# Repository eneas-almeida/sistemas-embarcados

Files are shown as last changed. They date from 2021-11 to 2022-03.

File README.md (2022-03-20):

# Sistemas Embarcados - 2021.2



## 1. Instituição

-   Instituto Federal da Paraíba - IFPB
-   Campus Campina Grande

## 2. Docente responsável

-   [Professor Dr. Alexandre Sales Vasconcelos](https://github.com/alexandresvifpb)

## 3. Grupo

-   [Edivam Enéas de Almeida Júnior](https://github.com/venzel)
-   [Erickson Tulio Rodrigues Azevêdo](https://github.com/Erickson-Eng)
-   [Joab da Silva Maia](https://github.com/JoabMaia)

## 4. Descrição do projeto

Nesse projeto foi realizado desenvolvimento de um sistema embarcado que é capaz de identificar vazamento de gases, além disso, também apresenta todas as informações desse vazamento a partir de um display led e faz envio de mensagens SMS para celulares cadastrados em uma aplicação integrada.

## 5. Objetivos

### 5.1. Geral

-   O objetivo geral deste trabalho é o desenvolvimento de uma hardware de segurança doméstica para fornecer um sinal de alarme ao usuário caso aconteça vazamento de gás, além de informações na tela de temperatura.

### 5.2. Específicos

-   Criar um prototipo que seja capaz de realizar detecção de gás, apresentação de resultados via display e também conseguir realizar envio de mensagens SMS para o dispositivo cadastrado.

## 6. Resumo das arquiteturas

A seguir é no tópico 1 _Hardware_ é apresentado a placa e o case ambos construídos no aplicativo fusion 360 e em seguida no tópico 2 _Firmaware e/ou Software/App_ é apresentado as especificações como circuito eletrico e PCB.

### 6.1. Desenhos

-   3D

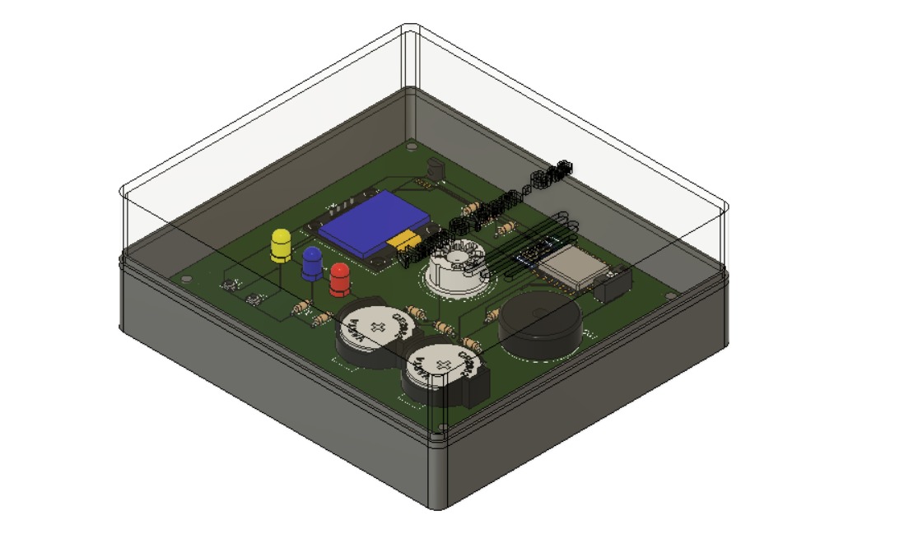
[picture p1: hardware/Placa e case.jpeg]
Placa e Case completo


-   PCB

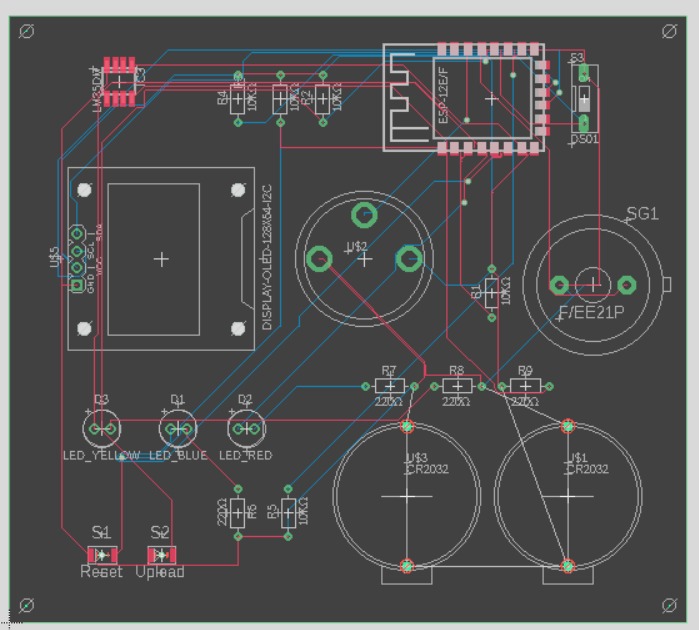
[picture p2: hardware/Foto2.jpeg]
foto


-   Circuito elétrico

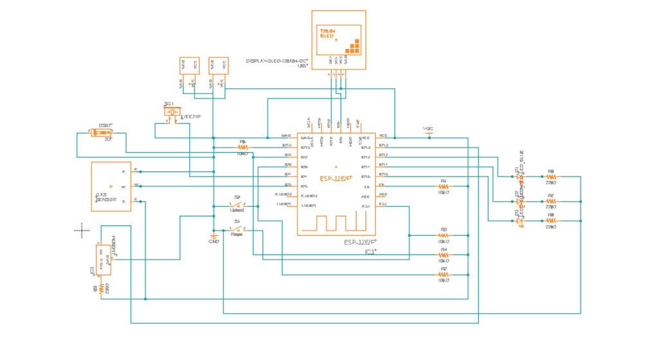
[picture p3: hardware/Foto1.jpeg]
foto 2


## 7. Firmwares

👉 [Teste do display lcd com I2C](./firmwares/teste_lcd_I2C/teste_lcd_I2C.ino)<br />
👉 [Teste do sensor de temperatura](./firmwares/teste_sensor_temperatura/teste_sensor_temperatura.ino)<br />
👉 [Teste do sensor de gás](./firmwares/teste_sensor-gas/teste_sensor-gas.ino)<br />
👉 [Teste da conexão com o wifi](./firmwares/teste_wifi/teste_wifi.ino)<br />
👉 [Código do projeto (v1)](./firmwares/codigo_final_projeto/codigo_final_projeto.ino)<br />
👉 [Código do projeto (v2)](./firmwares/projeto)

## 8. Vídeo do protótipo

Vídeo do protótipo (https://www.youtube.com/watch?v=XGZ1nPyMRSw)

## 9. Vídeo da apresentação

Vídeo do protótipo (https://www.youtube.com/watch?v=j182I6oHwiY)

## 10. Diagrama de processo

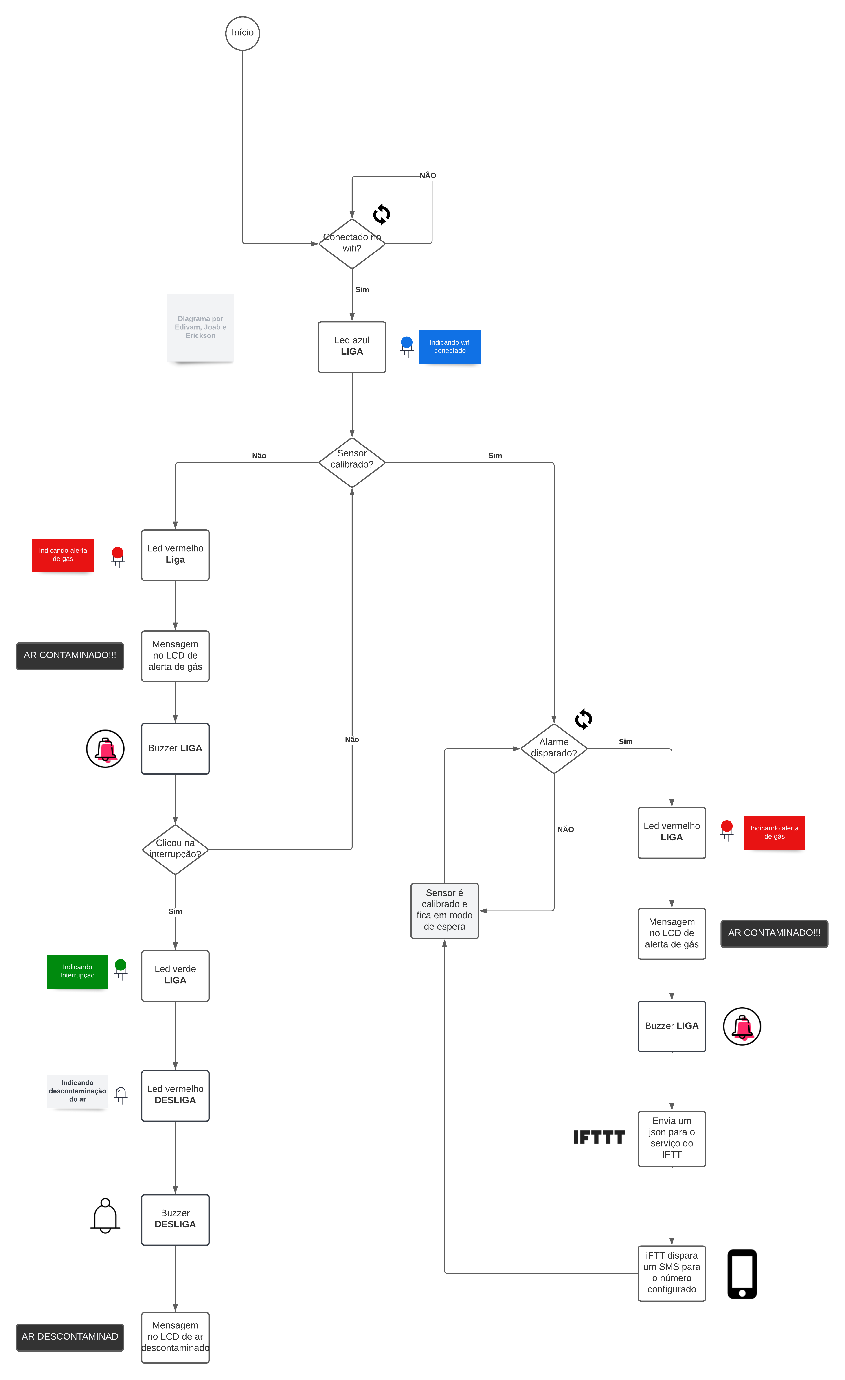
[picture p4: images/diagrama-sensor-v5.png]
Diagrama de processo


## 11. Diagrama de bloco

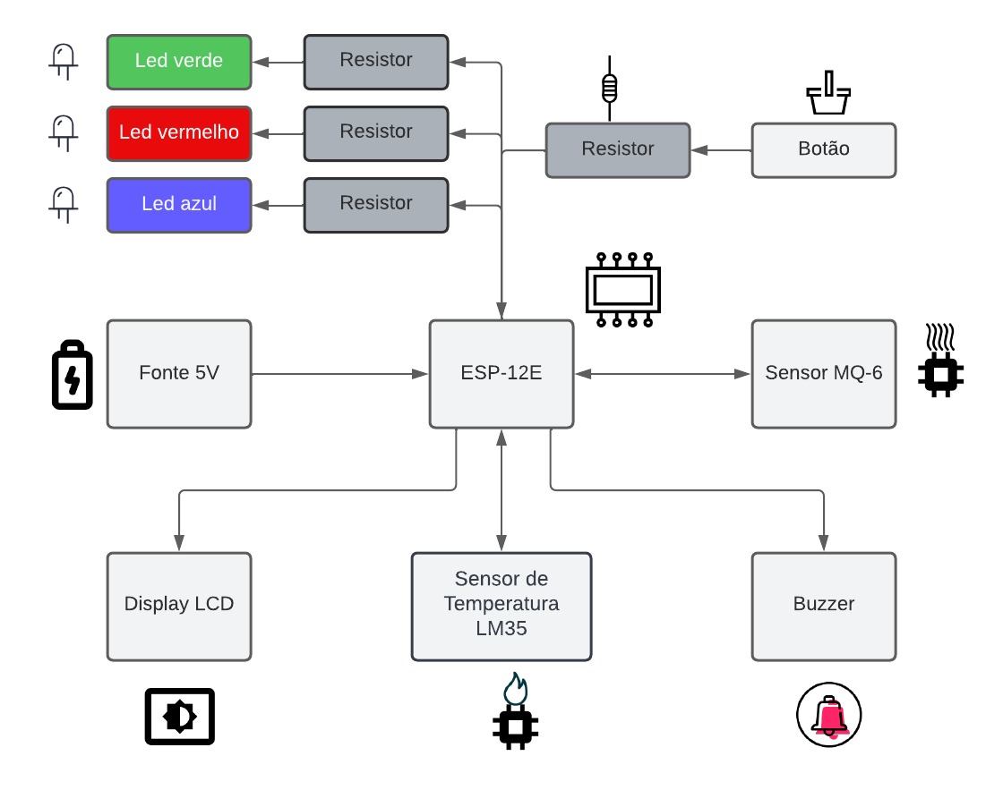
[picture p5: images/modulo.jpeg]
Diagrama de bloco


## 12. Resumo dos Resultados

Nesse projeto foi possível construir um protótipo capaz de realizar a detecção de gases inflamáveis, além disso, através do sistema é possível disparar alertas tanto para sua própria interface que é um componente LCD de 16 colunas e duas linhas, um alto-falante para emitir sinais sonoros e por fim interfaces externas com o uso de mensagem via SMS.



Outro recurso importante que também implementado foi a integração do sistema com uma api de envio de SMS, o **IFTT**, onde é possível através de uma chamada JSON, se comunicar com o serviço e efetuar disparos de SMS.

**Foi possível atingir os seguintes objetivos adicionais:**

-   Implementar sistema de interrupções.
-   Instalação de libs dos módulos.
-   Realizar a implementação de threads.

👉 [Relatório final do projeto (PDF)](./results/relatorio-final.pdf)<br />

## 13. Link dos arquivos

👉 [Esquema elétrico (EAGLE)](./3d/projeto_dispositivo_alarme_gas/esquema_eletrico/esquema_eletrico_eagle.sch)<br />
👉 [Esquema elétrico (FUSION)](./3d/projeto_dispositivo_alarme_gas/esquema_eletrico/esquema_eletrico_fusion.fsch)<br />
👉 [Imagens com furos da PCB (PARTE INFERIOR)](./3d/projeto_dispositivo_alarme_gas/imagem_bottom_side_da_pcb_manufacturing/imagem_bottom_side_da_pcb_manufacturing.png)<br />
👉 [Imagens com furos da PCB (PARTE SUPERIOR)](./3d/projeto_dispositivo_alarme_gas/imagem_top_side_da_pcb_manufacturing/imagem_top_side_da_pcb_manufacturing.png)<br />
👉 [Medidas dos furos da PCB (1)](./3d/projeto_dispositivo_alarme_gas/imagem_drils_da_pcb/imagem_drils_da_pcb.png)<br />
👉 [Medidas dos furos da PCB (2)](./3d/projeto_dispositivo_alarme_gas/imagem_drils_da_pcb/metricas_drills.csv)<br />
👉 [Layout da PCB (EAGLE)](./3d/projeto_dispositivo_alarme_gas/layout_da_pcb/layout_da_pcb_eagle.brd)<br />
👉 [Layout da PCB (FUSION)](./3d/projeto_dispositivo_alarme_gas/layout_da_pcb/layout_da_pcb_fusion.fbrd)<br />
👉 [Desenho 3D - Apenas PCB (FUSION)](./3d/projeto_dispositivo_alarme_gas/modelo_3d_da_pcb/modelo_3d_da_pcb.f3d)<br />
👉 [Desenho 3D - PCB + CASE (FUSION)](./3d/projeto_dispositivo_alarme_gas/modelo_3d_da_pcb/modelo_3d_da_pcb_e_case.f3z)

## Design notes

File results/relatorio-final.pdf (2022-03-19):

Instituto Federal de Educação, Ciência e Tecnologia da Paraíba.

Campus Campina Grande

Disciplina: Sistemas Embarcados

Professor: Alexandre Sales Vasconcelos

Equipe: Edivam Enéas de Almeida Junior,

Joab da Silva Maia,

Erickson Tulio Rodrigues Azevêdo.

# Sistema para monitorar vazamentos de gases e exposição

a alta temperaturas.

Resumo

Esse relatório tem como objetivo descrever o desenvolvimento do

protótipo que foi criado na disciplina de sistemas embarcados, no qual atua como

um sistema para prevenção de incêndios realizando a detecção de vazamento

de gases e, além disso, também verifica se existe aumentos de temperaturas

fora do normal no ambiente onde se encontra instalado. Para que tornasse

possível o desenvolvimento de tal solução foi necessário verificar o problema a

fundo e verificar sua viabilidade, dessa forma, realizamos uma pesquisa para

identificar o índice de acidentes domésticos e em empresas e decidimos a

abordagem que seria criar um sistema para uso doméstico.

Palavras-Chaves: | Esp32, | Prevenção | de | incêndios, | sistemas

embarcados, comunicação

### 1. Introdução

### 1.1. Acidentes domésticos com gás inflamável

Diante dos grandes acidentes causados, na maioria das vezes, por falta de

cuidados básicos e cumprimentos de normas técnicas a fim da prevenção de

acidentes e explosões causados por vazamentos de gás.

Dados estatísticos do corpo de bombeiros localizado no Estado de São

Paulo refletem bem essa problemática, enumerando os atendimentos prestados,

de simples vazamentos de botijões de gás até verdadeiras catástrofes causadas

por explosões residenciais (casas, prédios) e até mesmo nas indústrias.

Em meados de 2015, no Estado de São Paulo, o Corpo de Bombeiros

marcou 4.055 casos de acidentes por decorrência do vazamento do gás

conhecido como Gás Liquefeito de Petróleo ou simplesmente GLP. Como já

mencionado, isso se dá por pura negligência das pessoas que vão instalar uma

simples válvula em seu fogão até a falta de fiscalização das tubulações dos

grandes edifícios, empresas e fábricas.

A Figura 1 apresenta um exemplo do que pode causar problemas com

vazamento de gás, esse por sua vez ocorreu em 19 de outubro de 2015 no Bairro

de São Cristóvão, na Zona Norte do Rio de Janeiro.

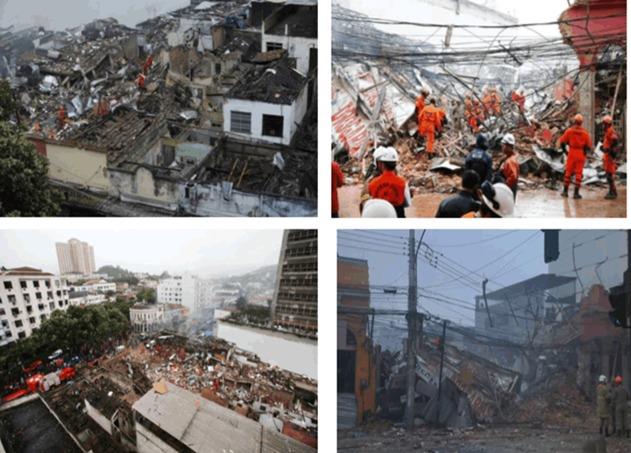
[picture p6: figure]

Figura 1. Acidente no Rio de Janeiro causado por vazamento de gás.

(Fonte: G1)

Nesse contexto, o objetivo desse trabalho é desenvolver um sistema

embarcado que seja capaz de realizar a detecção de gases e de aumentos da

temperatura e disparar alertas para assim, conseguir mais uma camada de

proteção e prevenção para população para esse tipo de acidentes.

### 2. Metodologia

O presente trabalho apresenta o desenvolvimento de um protótipo de

sistema embarcado cujo o público alvo são ambientes domésticos. Para obter

um melhor embasamento cientifico, foram realizados estudos bibliográficos para

conhecer os riscos do gás GLP, além disso, foram realizados levantamento

sobre as ferramentas e tecnologias necessárias para a construção do mesmo.

### 2.1. Tecnologias

Durante o desenvolvimento do projeto foi realizado um levantamento de

todos os materiais que seriam necessários para fazer um protótipo útil e funcional onde após realizar a instalação do mesmo no local apropriado seria possível

obter os devidos resultados.

### 2.1.1. Lista dos principais materiais utilizados para

produção do protótipo

- Módulo NodeMCU ESP-12E - é uma placa que junta o

ESP8266 (chip de arquitetura 32 bits com WiFi integrado), interface USB-

Serial e regulador de tensão 3,3V. A programação pode ser feita usando

LUA ou a IDE do Arduino, utilizando a comunicação via cabo micro-usb

- Sensor de MQ-6 - é um detector de gás inflamável é usado

como dispositivo de segurança em projetos de automação residencial que

usam como base plataformas de prototipagem, como Arduino ou

Raspberry PI.

- Buzzer - é um pequeno alto-falante destinado a emitir sinais

sonoros a partir do fornecimento de 5V DC ao módulo, não necessita de

nenhum componente externo para gerar sinal ou oscilação, basta

alimentar com corrente

- Display LCD 16x2 Backlight Azul - é um visor de 16

colunas por 2 linhas, backlight azul e escrita branca. Possui o controlador

HD44780 usado em toda indústria de LCD’s como base de interface.

- I2C para Display LCD - este é um módulo para

comunicação por protocolo I2C, é utilizado em displays LCD 16X2 ou

20x4. Com este módulo é possível ocupar apenas duas portas do

microcontrolador, pois dos quatro pinos de saída, dois são para

alimentação de 5Volts. DHT11 - Este sensor é ideal para fazer a leitura

de umidade e temperatura e informar ao microcontrolador como um

Arduino. Ele possui saída de sinal digital garantindo alta confiabilidade e

estabilidade a longo prazo.

- Protoboard - Uma placa de ensaio ou matriz de contato,

(breadboard em inglês) é uma placa com furos (ou orifícios) e conexões

condutoras para montagem de circuitos elétricos experimentais

- Leds – Utilizados para sinalização visual.
- Resistores de 300 ohms

- Jumper tipo macho-macho e macho-fêmea – Utilizado

para conectar os componentes do protótipo.

- Caixa em MDF – Utilizados para criar um suporte para os

sensores e Shields do protótipo.

Figura 2 Diagrama de protótipo

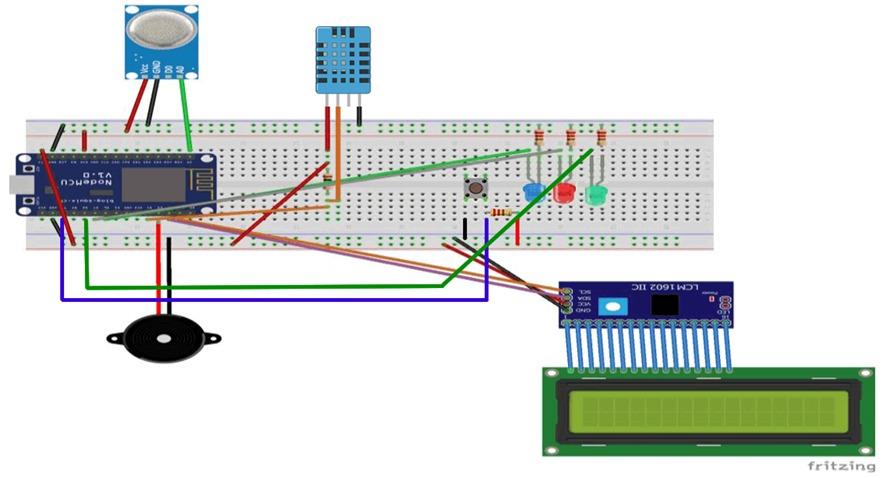
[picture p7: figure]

Fonte 1 Elaborado pelo autor (2022)

Na Figura 2 é apresentado a organização inicial de como ficará o protótipo

ao realizar todas as ligações entre os componentes em sua versão inicial.

Desenvolvimento

### 2.2. O protótipo

Esse projeto possui como diferencial a criação de um sistema de baixo

custo de produção para conseguir atender pessoas em situação social critica.

Para isso, se fez necessário identificar quais os cenários que nosso protótipo

conseguiria atuar.

Na Figura 3 é apresentado um fluxograma do funcionamento do sistema

demonstrando sua linha de raciocínio para suas decisões a ações.

Figura 3- Fluxograma do funcionamento do sistema

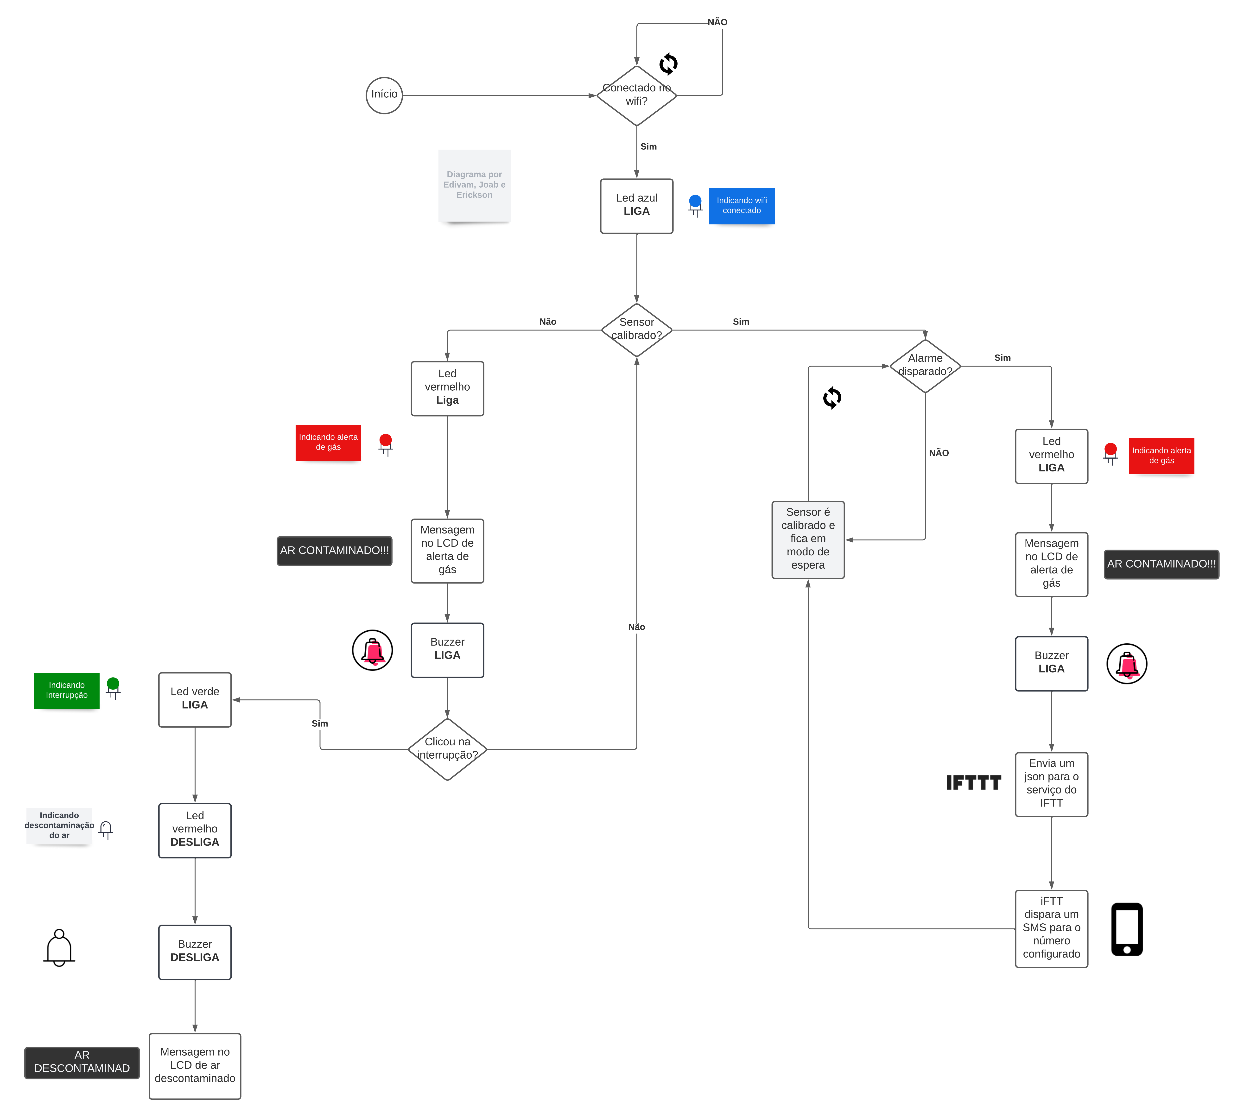
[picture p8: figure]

Fonte 2- Elaborado pelos autores (2022)

Na Figura 3 é possível verificar o funcionamento do sistema onde o

mesmo precisa se conectar com uma rede wifi para realizar a calibragem dos

sensores. Após todo o sistema estar calibrado o mesmo passa a realizar

verificação do ar buscando princípios de contaminação, caso exista

contaminação o sistema dispara duas ações onde é a primeira é alerta sonoro e

iniciado em seguida também um contato com sistema de envio de mensagens

SMS para envio de um relatório para o numero cadastrado no sistema

informando sobre a contaminação ou alteração na temperatura no local que está

instalado o protótipo.

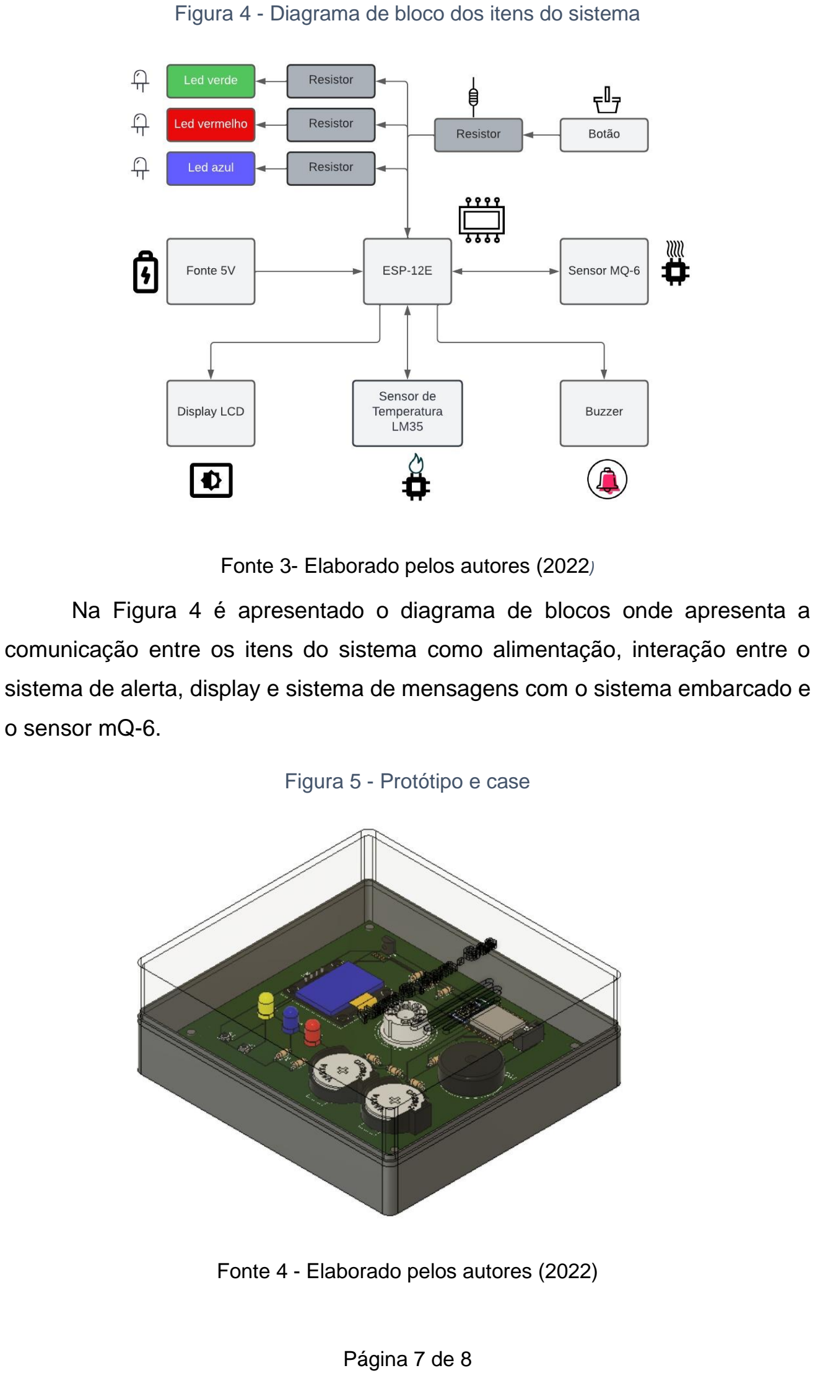
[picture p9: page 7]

Figura 4 - Diagrama de bloco dos itens do sistema

Fonte 3- Elaborado pelos autores (2022)

Na Figura 4 é apresentado o diagrama de blocos onde apresenta a

comunicação entre os itens do sistema como alimentação, interação entre o

sistema de alerta, display e sistema de mensagens com o sistema embarcado e

o sensor mQ-6.

Figura 5 - Protótipo e case

Fonte 4 - Elaborado pelos autores (2022)

Na Figura 5 é apresentado uma imagem do protótipo 3d criada no Fusion 360 onde representa o objeto desse estudo mostrando como ficará organizado como um produto.

### 3. Resultados

O presente trabalho teve como objetivos propor e desenvolver um sistema

embarcado capaz de identificar se existe contaminação no ar e em prontidão

passar a informação para seu usuário seja por mensagem de texto ou alerta

sonoros.

Esses objetivos foram alcançados, além disso, foi proposto também pelo

professor Alexandre a implementação de threads e um sistema de interrupções

no desenvolvimento no iria possibilitar melhorias que também foram

prontamente realizadas.

Para desenvolvimento futuro fica o desafio de montar um sistema de baixo

custo que possibilite realizar mais ações além das citadas nessa problemática

como o controle do fluxo de gás do fogão.

### 4. Referências bibliográficas

https://www.arduino.cc/reference/pt/

http://automatizacg.com

http://fritzing.org/home

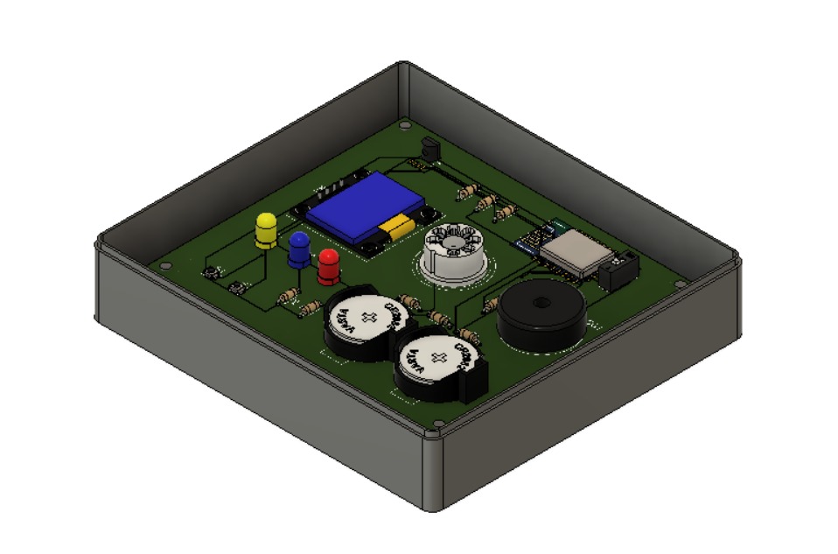
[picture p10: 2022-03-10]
hardware/Placa sem case superior.jpeg

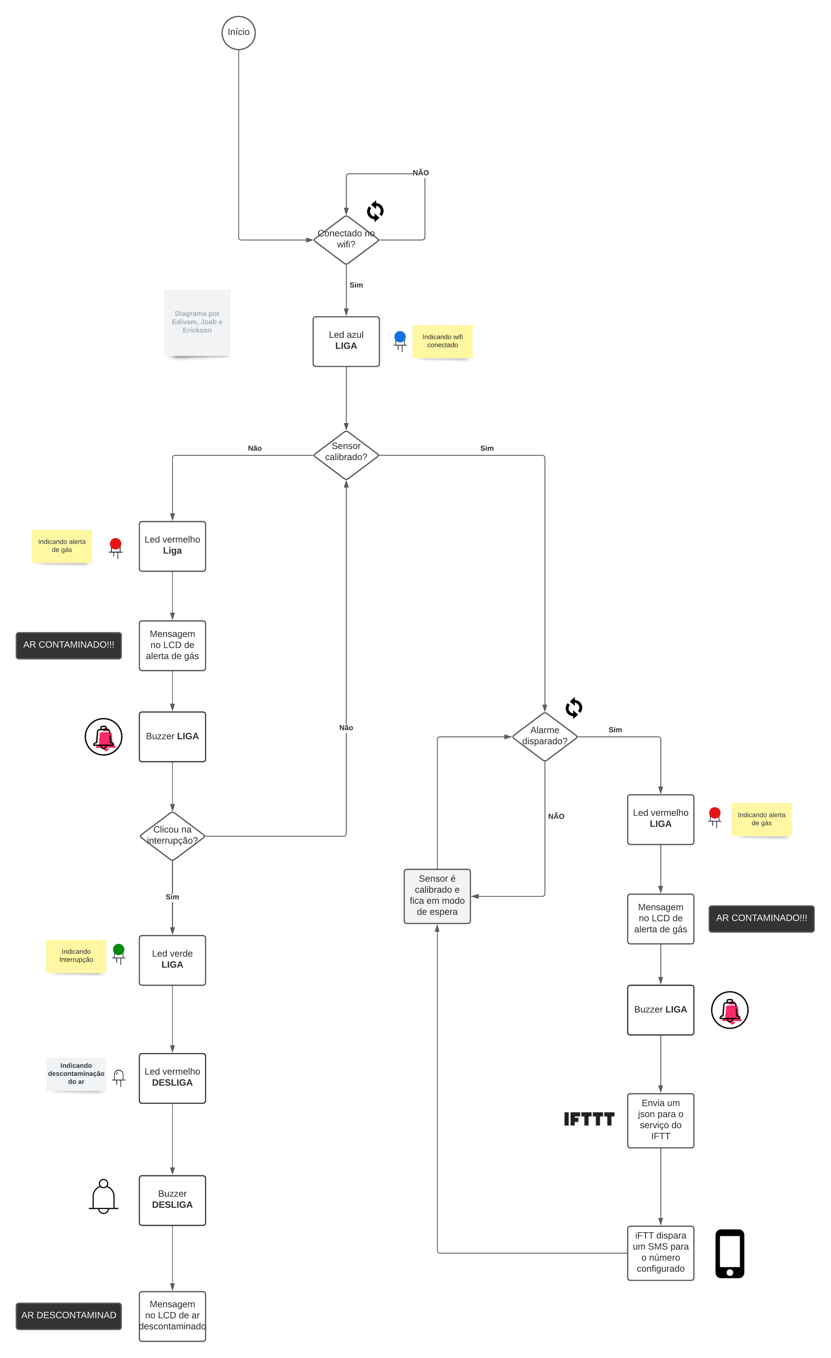
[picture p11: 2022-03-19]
images/diagrama-sensor-v4.png

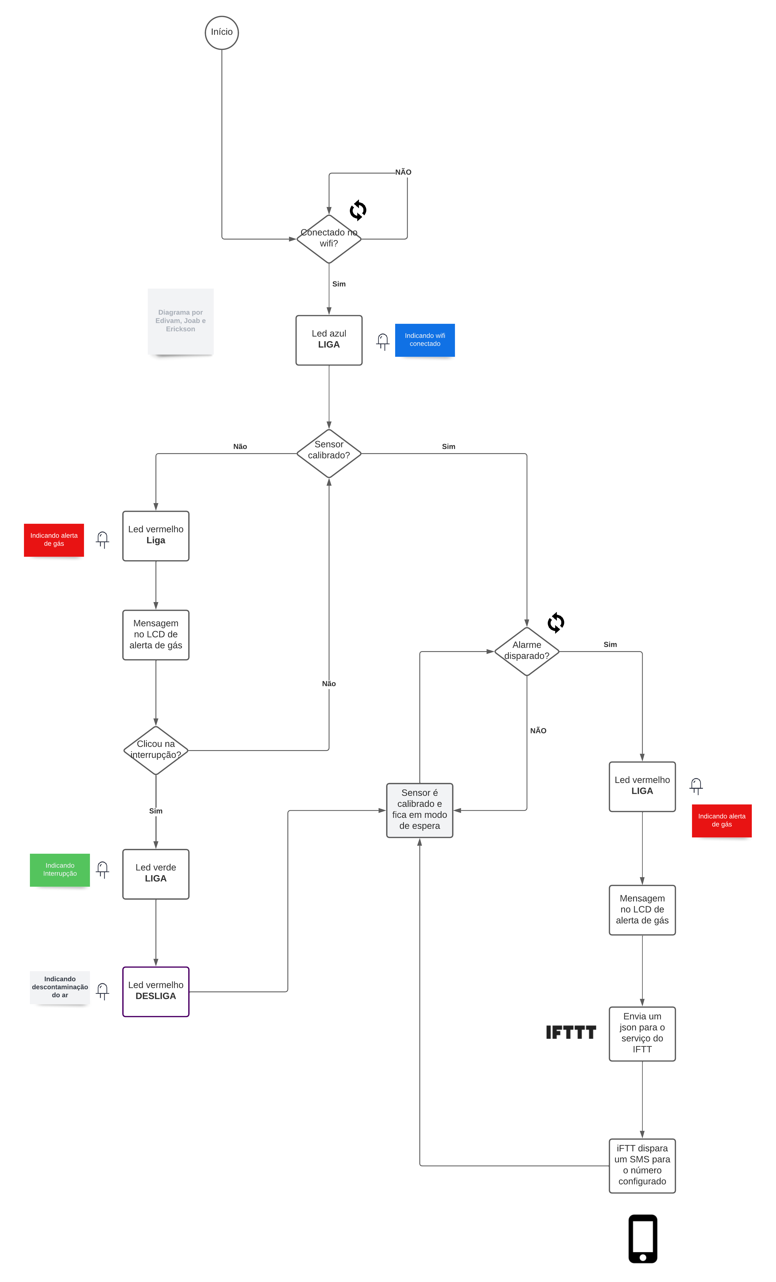
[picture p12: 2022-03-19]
images/diagrama-sensor-v2.png

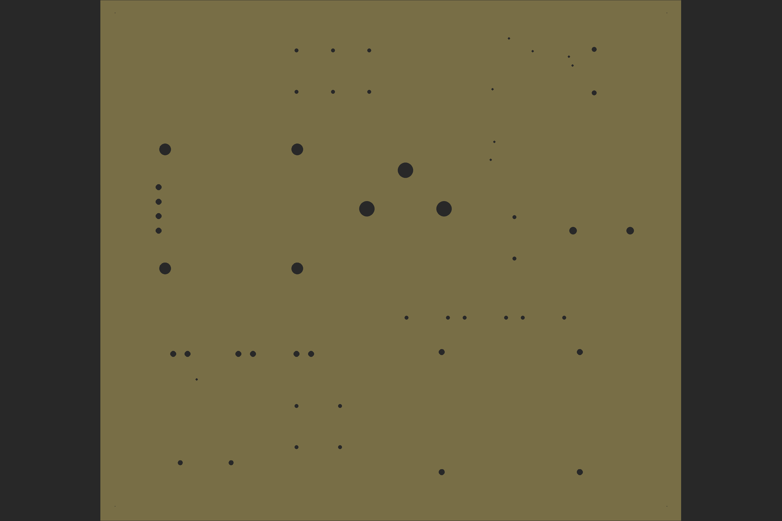
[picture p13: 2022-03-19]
3d/projeto_dispositivo_alarme_gas/imagem_drils_da_pcb/imagem_drils_da_pcb.png

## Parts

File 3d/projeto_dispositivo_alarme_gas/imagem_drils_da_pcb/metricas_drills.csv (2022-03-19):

via | NPTH | PTH | count | start_layer | end_layer | metric_min_mm | metric_max_mm | imperial_min_in | imperial_max_in | positions_mm | positions_in
false | false | true | 3 | 1 | 16 | 2.667000 | 2.667000 | 0.105000 | 0.105000 | (53.340000 61.360000)(60.090000 54.610000)(46.590000 54.610000) | (2.100000 2.415748)(2.365748 2.150000)(1.834252 2.150000)
false | true | false | 4 | 1 | 16 | 2.000000 | 2.000000 | 0.078740 | 0.078740 | (11.303000 44.196000)(11.303000 65.024000)(34.417000 65.024000)(34.417000 44.196000) | (0.445000 1.740000)(0.445000 2.560000)(1.355000 2.560000)(1.355000 1.740000)
false | false | true | 2 | 1 | 16 | 1.320800 | 1.320800 | 0.052000 | 0.052000 | (92.633800 50.800000)(82.626200 50.800000) | (3.647000 2.000000)(3.253000 2.000000)
false | true | true | 8 | 1 | 16 | 1.000000 | 1.000000 | 0.039370 | 0.039370 | (83.820000 8.550000)(83.820000 29.550000)(59.690000 29.550000)(59.690000 8.550000)(10.160000 50.800000)(10.160000 53.340000)(10.160000 55.880000)(10.160000 58.420000) | (3.300000 0.336614)(3.300000 1.163386)(2.350000 1.163386)(2.350000 0.336614)(0.400000 2.000000)(0.400000 2.100000)(0.400000 2.200000)(0.400000 2.300000)
false | false | true | 6 | 1 | 16 | 0.981000 | 0.981000 | 0.038622 | 0.038622 | (24.130000 29.210000)(26.670000 29.210000)(34.290000 29.210000)(36.830000 29.210000)(12.700000 29.210000)(15.240000 29.210000) | (0.950000 1.150000)(1.050000 1.150000)(1.350000 1.150000)(1.450000 1.150000)(0.500000 1.150000)(0.600000 1.150000)
false | true | false | 2 | 1 | 16 | 0.850000 | 0.850000 | 0.033465 | 0.033465 | (22.860000 10.160000)(13.970000 10.160000) | (0.900000 0.400000)(0.550000 0.400000)
false | false | true | 2 | 1 | 16 | 0.812800 | 0.812800 | 0.032000 | 0.032000 | (86.360000 82.550000)(86.360000 74.930000) | (3.400000 3.250000)(3.400000 2.950000)
false | false | true | 4 | 1 | 16 | 0.800000 | 0.800000 | 0.031496 | 0.031496 | (83.820000 29.550000)(83.820000 8.550000)(59.690000 29.550000)(59.690000 8.550000) | (3.300000 1.163386)(3.300000 0.336614)(2.350000 1.163386)(2.350000 0.336614)
false | false | true | 18 | 1 | 16 | 0.660000 | 0.660000 | 0.025984 | 0.025984 | (34.290000 12.890000)(53.530000 35.560000)(60.770000 35.560000)(63.690000 35.560000)(70.930000 35.560000)(73.850000 35.560000)(81.090000 35.560000)(72.390000 45.910000)(72.390000 53.150000)(46.990000 75.120000)(46.990000 82.360000)(40.640000 75.120000)(40.640000 82.360000)(34.290000 75.120000)(34.290000 82.360000)(41.910000 12.890000)(41.910000 20.130000)(34.290000 20.130000) | (1.350000 0.507480)(2.107480 1.400000)(2.392520 1.400000)(2.507480 1.400000)(2.792520 1.400000)(2.907480 1.400000)(3.192520 1.400000)(2.850000 1.807480)(2.850000 2.092520)(1.850000 2.957480)(1.850000 3.242520)(1.600000 2.957480)(1.600000 3.242520)(1.350000 2.957480)(1.350000 3.242520)(1.650000 0.507480)(1.650000 0.792520)(1.350000 0.792520)
true | false | false | 8 | 1 | 16 | 0.350000 | 0.350000 | 0.013780 | 0.013780 | (16.827500 24.765000)(75.565000 82.232500)(71.437500 84.455000)(68.580000 75.565000)(68.897500 66.357500)(68.262500 63.182500)(81.915000 81.280000)(82.550000 79.692500) | (0.662500 0.975000)(2.975000 3.237500)(2.812500 3.325000)(2.700000 2.975000)(2.712500 2.612500)(2.687500 2.487500)(3.225000 3.200000)(3.250000 3.137500)
false | true | false | 4 | 1 | 16 | 0.076200 | 0.076200 | 0.003000 | 0.003000 | (2.540000 88.900000)(2.540000 2.540000)(99.060000 2.540000)(99.060000 88.900000) | (0.100000 3.500000)(0.100000 0.100000)(3.900000 0.100000)(3.900000 3.500000)

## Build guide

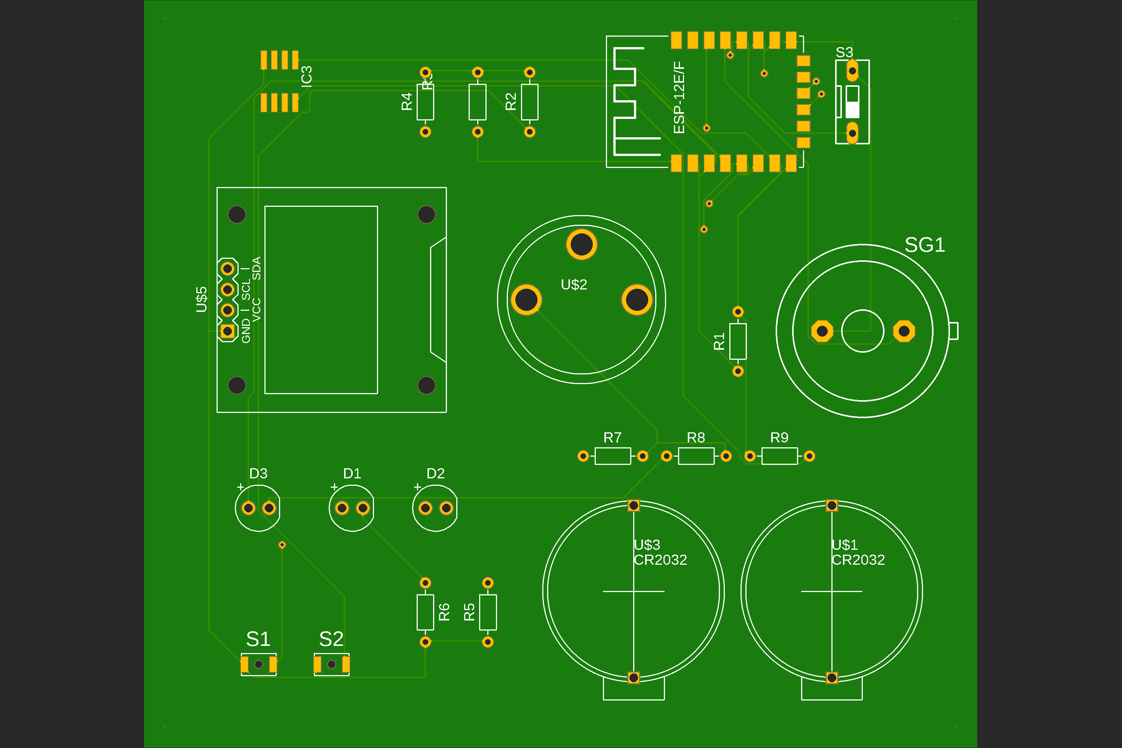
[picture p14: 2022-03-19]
3d/projeto_dispositivo_alarme_gas/imagem_top_side_da_pcb_manufacturing/imagem_top_side_da_pcb_manufacturing.png

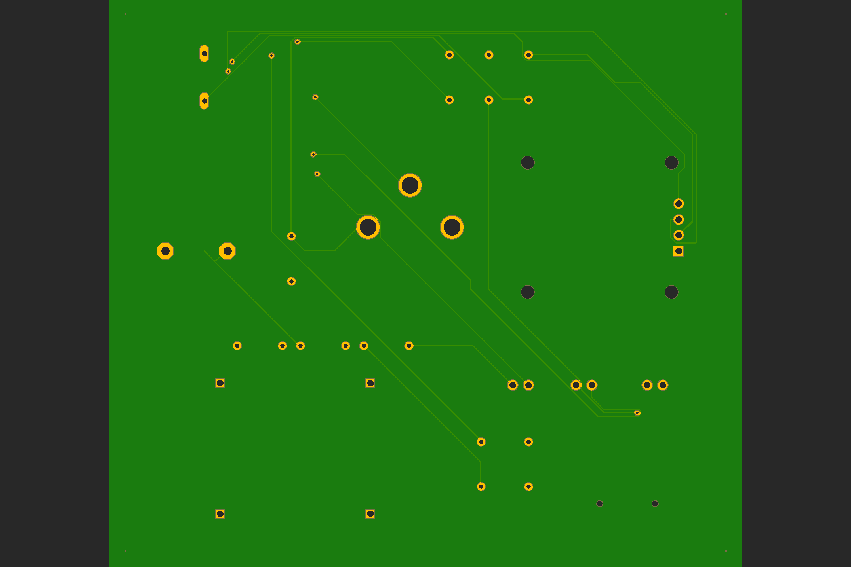
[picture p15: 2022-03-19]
3d/projeto_dispositivo_alarme_gas/imagem_bottom_side_da_pcb_manufacturing/imagem_bottom_side_da_pcb_manufacturing.png

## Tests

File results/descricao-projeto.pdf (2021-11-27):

IFPB - Instituto Federal de Educação, Ciência e Tecnologia da Paraíba

Disciplina: Sistemas Embarcados

Professor: Alexandre Sales Vasconcelos

Equipe: Joab da Silva Maia, | Edivam Enéas de Almeida Júnior, | Erickson Tulio
| Rodrigues Azevêdo (https://github.com/Erickson-Eng)

Dispositivo de alerta de gás inflamável e temperatura

### 1. INTRODUÇÃO

Diante dos grandes acidentes causados, na maioria das vezes, por falta de cuidados básicos e cumprimentos de normas técnicas a fim da prevenção de acidentes e explosões causados por vazamentos de gás.

Dados estatísticos do corpo de bombeiros localizado no Estado de São Paulo refletem bem essa problemática, enumerando os atendimentos prestados, de simples vazamentos de botijões de gás até verdadeiras catástrofes causadas por explosões residenciais (casas, prédios) e até mesmo nas indústrias.

Em meados de 2015, no Estado de São Paulo, o Corpo de Bombeiros marcou 4.055 casos de acidentes por decorrência do vazamento do gás conhecido como Gás Liquefeito de Petróleo ou simplesmente GLP. Como já mencionado, isso se dá por pura negligência das pessoas que vão instalar uma simples válvula em seu fogão até a falta de fiscalização das tubulações dos grandes edifícios, empresas e fábricas. Abaixo segue um exemplo real que ocorreu em 19 de outubro de 2015 no Bairro de São Cristóvão, na Zona Norte do Rio de Janeiro.

Abaixo segue um exemplo real que ocorreu em 19 de outubro de 2015 no Bairro de São Cristóvão, na Zona Norte do Rio de Janeiro.

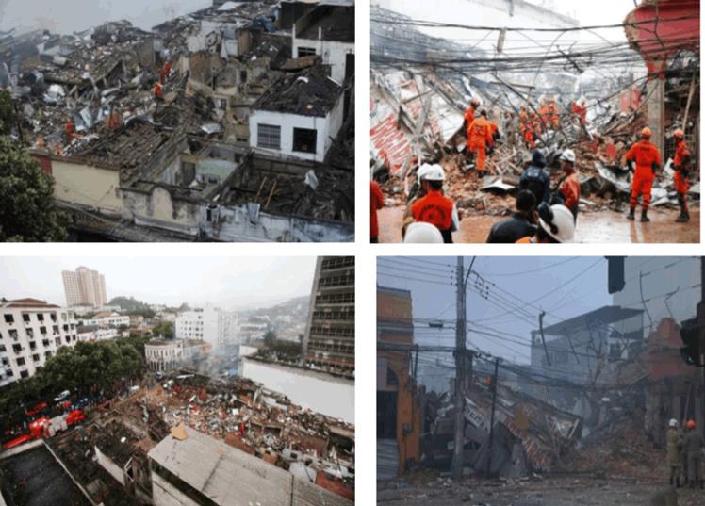
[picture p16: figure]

Figura 1. Acidente no Rio de Janeiro causado por vazamento de gás. (Fonte: G1)

Diante do exposto, e no intuito de iniciar um estudo para posteriores desenvolvimentos sob o mesmo tema, este projeto objetivou-se em mostrar a importância da detecção de gases inflamáveis, mediante sensor MQ-2, agregando dispositivos de alertas, na finalidade de prevenir de acidentes de grandes proporções, protegendo assim à vida humana.

### 2. DESENVOLVIMENTO

### 2.1. Materiais principais utilizados e respectivas definições

Módulo NodeMCU ESP-12E - é uma placa que junta o ESP8266 (chip de arquitetura 32 bits com WiFi integrado), interface USB-Serial e regulador de tensão 3,3V. A programação pode ser feita usando LUA ou a IDE do Arduino, utilizando a comunicação via cabo micro-usb.

Sensor de MQ-6 - é um detector de gás inflamável é usado como dispositivo de segurança em projetos de automação residencial que usam como base plataformas de prototipagem, como Arduino ou Raspberry PI.

O Buzzer Ativo - é um pequeno alto-falante destinado a emitir sinais sonoros a partir do fornecimento de 5V DC ao módulo, não necessita de nenhum componente externo para gerar sinal ou oscilação, basta alimentar com corrente contínua.

Display LCD 16×2 Backlight Azul – é um visor de 16 colunas por 2 linhas, backlight azul e escrita branca. Possui o controlador HD44780 usado em toda indústria de LCD’s como base de interface.

I2C para Display LCD - este é um módulo para comunicação por protocolo I2C, é utilizado em displays LCD 16X2 ou 20x4. Com este módulo é possível ocupar apenas duas portas do microcontrolador, pois dos quatro pinos de saída, dois são para alimentação de 5Volts. DHT11 - Este sensor é ideal para fazer a leitura de umidade e temperatura e informar ao microcontrolador como um Arduino. Ele possui saída de sinal digital garantindo alta confiabilidade e estabilidade a longo prazo.

Protoboard - Uma placa de ensaio ou matriz de contato, (breadboard em inglês) é uma placa com furos (ou orifícios) e conexões condutoras para montagem de circuitos elétricos experimentais.

### 2.2. Materiais secundários utilizados

- Leds;
- Resistores de 300 ohms;
- Botão pullup para interrupção;
- Jumpers para conexão do tipo macho-macho e macho-fêmea;
- Pequena caixa em MDF para suporte aos sensores e shields utilizados;
- Pistola de cola-quente;

- Fita adesiva 3M.

### 2.3. Ferramentas utilizadas

- Furadeira/Retífica para perfuração e encaixe dos shields e leds;
- Estilete;
- Tesoura;
- Alicates.

### 2.4. Diagrama do dispositivo de alerta

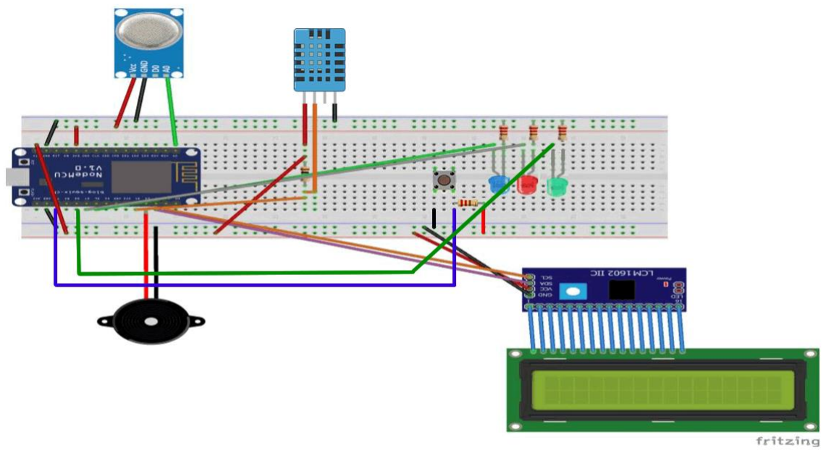
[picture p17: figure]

Figura 2. Diagrama do protótipo montado no protoboard.

Fonte de referências

https://www.arduino.cc/reference/pt/

http://automatizacg.com

http://fritzing.org/home

http://g1.globo.com/rio-de-janeiro/noticia/2015/10/vazamento-de-gas-e-

consenso-entre-autoridades-sobre-causa-de-explosao.html

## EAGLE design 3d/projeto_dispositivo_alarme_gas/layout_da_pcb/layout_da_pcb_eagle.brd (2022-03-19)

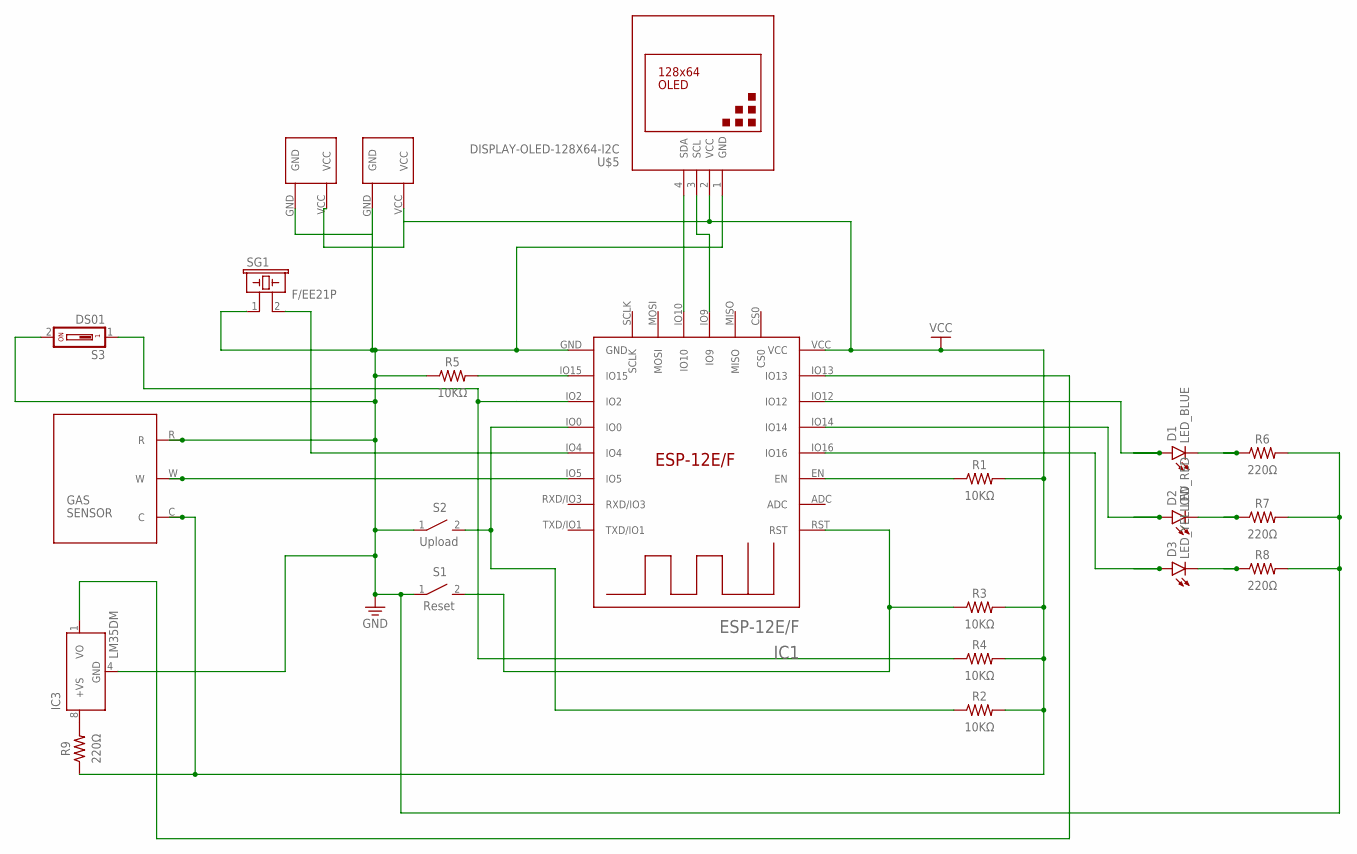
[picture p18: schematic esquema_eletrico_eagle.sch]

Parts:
D1: LED_BLUE; LEDRD254W60D565H860B_B
D2: LED_RED; LEDRD254W60D565H860B
D3: LED_YELLOW; LEDRD254W60D565H860B_Y
IC1: ESP-12E/F; ESP-12E
IC3: LM35DM; SO08
R1, R2, R3, R4, R5: 10KΩ; RESAD724W46L381D178B
R6, R7, R8, R9: 220Ω; RESAD724W46L381D178B
S1: Reset; B3U-1000P(M)-B
S2: Upload; B3U-1000P(M)-B
S3: DS01; DS-01
SG1: F/EE21P
U$1, U$3: CR2032; CR2032-20MM
U$2: 3-ELECTRODE-GAS-SENSOR; 3-ELECTRODE
U$5: DISPLAY-OLED-128X64-I2C

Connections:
GND: IC1.GND, IC3.4 (GND), R5.1, R6.2, R7.2, R8.2, S1.1, S2.1, S3.2, SG1.1, U$1.GND, U$2.R, U$3.GND, U$5.1 (GND)
unnamed: IC1.RST, R3.1, S1.2
unnamed: IC1.IO15, R5.2
unnamed: IC1.EN, R1.1
unnamed: IC1.IO2, R4.1, S3.1
unnamed: IC1.IO0, R2.1, S2.2
unnamed: IC1.IO4, SG1.2
unnamed: IC1.IO5, U$2.W
unnamed: IC1.IO13, IC3.1 (VO)
unnamed: D1.1 (A), IC1.IO12
unnamed: D2.1 (A), IC1.IO14
unnamed: D3.1 (A), IC1.IO16
unnamed: D1.2 (C), R6.1
unnamed: D2.2 (C), R7.1
unnamed: D3.2 (C), R8.1
unnamed: IC3.8 (+VS), R9.2
unnamed: IC1.IO10, U$5.4 (SDA)
unnamed: IC1.IO9, U$5.3 (SCL)
VCC: IC1.VCC, R1.2, R2.2, R3.2, R4.2, R9.1, U$1.VCC, U$2.C, U$3.VCC, U$5.2 (VCC)

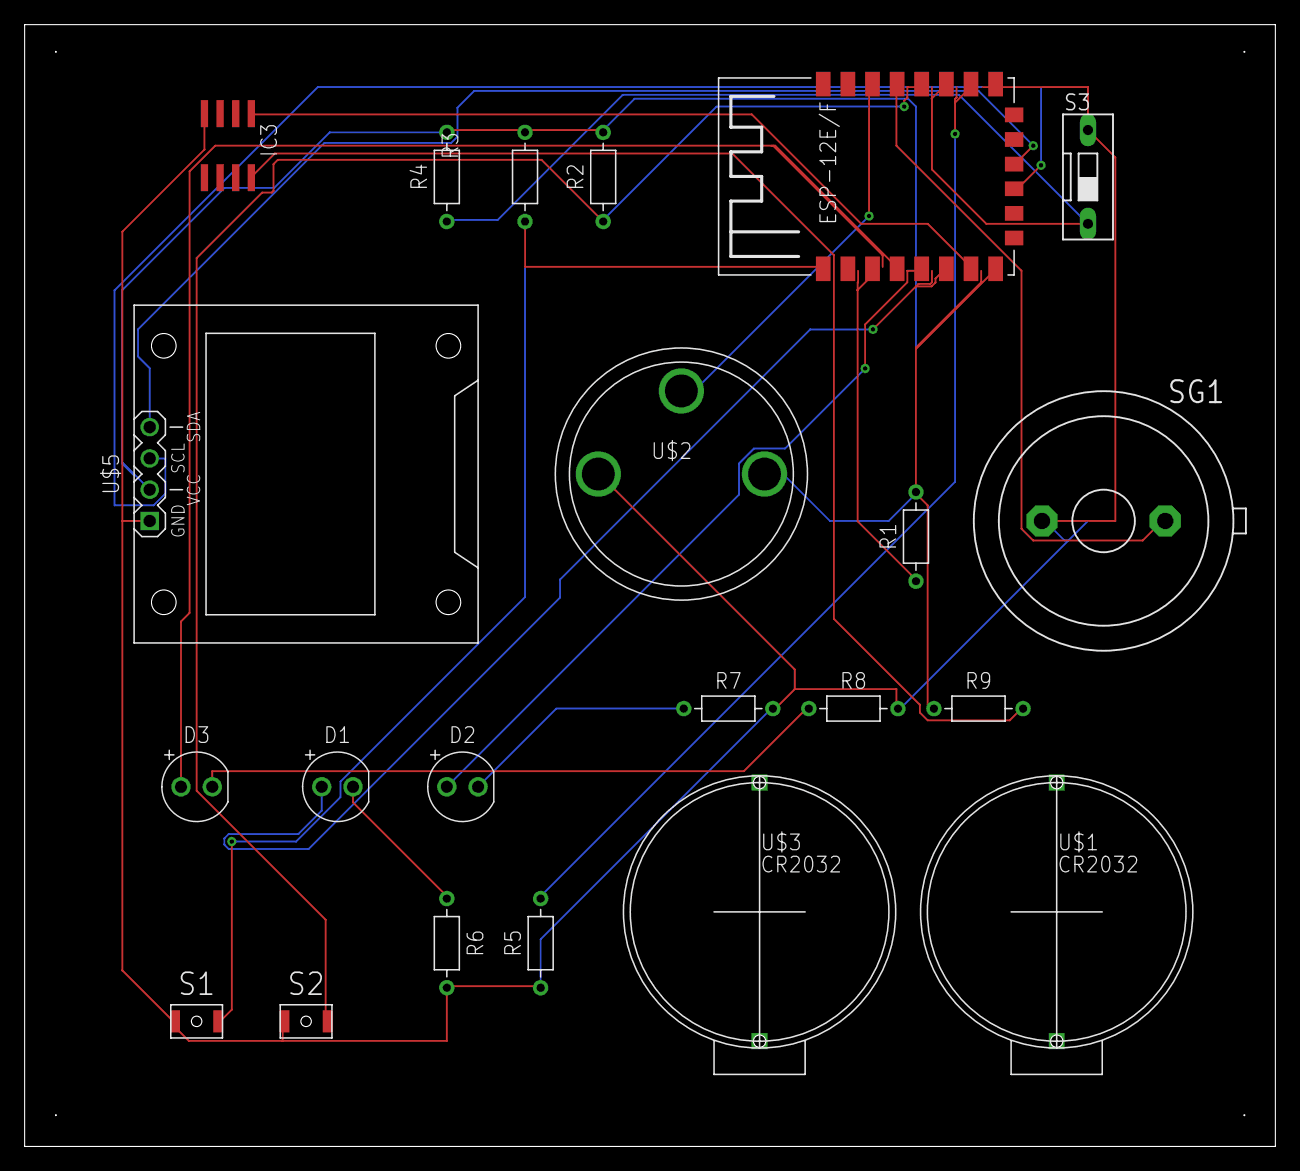
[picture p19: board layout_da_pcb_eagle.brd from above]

Board: 2 copper layers, 101.6 x 91.1 mm, 22 parts (0 on the bottom side), 19 nets.

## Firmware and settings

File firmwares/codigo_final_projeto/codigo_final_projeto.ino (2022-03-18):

#include <ESP8266WiFi.h>
#include <Wire.h>
#include <LiquidCrystal_I2C.h>
#include <DHT.h>

LiquidCrystal_I2C lcd(0x3F, 2, 1, 0, 4, 5, 6, 7, 3, POSITIVE);

WiFiClient client;

String chave_servico;

String evento_servico;

char *append_str(char *here, String s) {
  int i=0;
  
  while (*here++ = s[i]){i++;};
  
  return here-1;
}

char *append_ul(char *here, unsigned long u) {
  char buf[20];
  return append_str(here, ultoa(u, buf, 10));
}

char post_rqst[256];
char *p;
char *content_length_here;
char *json_start;
int compi;

// PINAGEM
#define PIN_SENSOR_GAS A0
#define PIN_SENSOR_TMP D4
#define PIN_BUZZER D3
#define PIN_DHT D4
#define PIN_LED_LAN D6
#define PIN_LED_ALERTA D7
#define PIN_LED_INT D8
#define PIN_INT D10
#define TIPO_SENSOR DHT11

DHT dht(PIN_DHT, TIPO_SENSOR);

// VARIAVEIS
#define AVG 10000.0
#define TAXA_GAS_MAX 8.0
#define TAXA_TEMP_MAX 35

// GLOBAIS
float sensor_volt;
float valorSensor;
float RS_gas;
float R0;
float taxa;

// GLOBAL
bool sms_enviado = false;
int temperatura;

void ICACHE_RAM_ATTR calibracaoX();

void envia_sms()
{
  if (client.connect("maker.ifttt.com", 80))
  {
    chave_servico = "cTRgedBgpB_uka5vJfFoSZ";
    evento_servico = "sms_micro";
    p = post_rqst;
    p = append_str(p, "POST /trigger/");
    p = append_str(p, evento_servico);
    p = append_str(p, "/with/key/");
    p = append_str(p, chave_servico);
    p = append_str(p, " HTTP/1.1\r\n");
    p = append_str(p, "Host: maker.ifttt.com\r\n");
    p = append_str(p, "Content-Type: application/json\r\n");
    p = append_str(p, "Content-Length: ");
    content_length_here = p;
    p = append_str(p, "NN\r\n");
    p = append_str(p, "\r\n");
    json_start = p;
    p = append_str(p, "{\"value1\":\"");
    p = append_str(p, "ALERTA DE GAS!!!");
    p = append_str(p, "\",\"value2\":\"");
    p = append_str(p, "ALERTA DE GAS!!!");
    p = append_str(p, "\",\"value3\":\"");
    p = append_str(p, "");
    p = append_str(p, "\"}");

    compi= strlen(json_start);
    content_length_here[0] = '0' + (compi/10);
    content_length_here[1] = '0' + (compi%10);
    client.print(post_rqst);
    Serial.println("SMS enviado!!!");
    Serial.println(post_rqst);
  }
}

void setup()
{
  Serial.begin(9600);
  lcd.begin(16, 2);
  dht.begin();

  WiFi.disconnect();

  sms_enviado = false;

  // Entradas
  pinMode(PIN_SENSOR_GAS, INPUT);
  pinMode(PIN_SENSOR_TMP, INPUT);
  pinMode(PIN_INT, INPUT);

  // Leds
  pinMode(PIN_LED_INT, OUTPUT);
  pinMode(PIN_LED_ALERTA, OUTPUT);
  pinMode(PIN_LED_LAN, OUTPUT);

  // Buzzer
  pinMode(PIN_BUZZER, OUTPUT);

  // Nivel baixo dos leds
  digitalWrite(PIN_LED_INT, LOW);
  digitalWrite(PIN_LED_ALERTA, LOW);
  digitalWrite(PIN_LED_LAN, LOW);

  // Seta a interrupcao
  attachInterrupt(digitalPinToInterrupt(PIN_INT), calibracaoX, RISING);

  // Executa a funcao de calibracao
  calibracaoX();
  
  lcd.setBacklight(HIGH);
  
  lcd.setCursor(0, 0);
  
  lcd.print("INICIANDO.");

  for(int i=0; i<=2; i++)
  {
    delay(1000);
    lcd.print(".");
  }
  
  delay(1000);

  lcd.clear();

  lcd.print("CONECTANDO");
 
  WiFi.begin("eneas", "penadepato");
  
  while((!(WiFi.status() == WL_CONNECTED)))
  {
    delay(2000);
    lcd.print(".");
  }

  lcd.clear();

  digitalWrite(PIN_LED_LAN, HIGH);
  digitalWrite(PIN_BUZZER, HIGH);
  delay(100);
  digitalWrite(PIN_BUZZER, LOW);

  lcd.print("CONECTADO!!!");

  delay(3000);

  lcd.clear();

  lcd.print("VERIFICANDO AR");

  for(int i=0; i<=2; i++)
  {
    delay(2000);
    lcd.print(".");
  }

  lcd.clear();
  
  lcd.print("AR DESCONTAMINAD");
}

void loop()
{
  valorSensor = analogRead(PIN_SENSOR_GAS);
  temperatura = dht.readTemperature();
  
  sensor_volt = (float) valorSensor / 1024*5.0;
  RS_gas = (5.0-sensor_volt) / sensor_volt;
  taxa = RS_gas / R0;
  
  if (taxa <= TAXA_GAS_MAX)
  {

    if (sms_enviado == false)
    {
      envia_sms();
    }
  
    sms_enviado = true;
    
    alarme("gas", true);
  }
  else
  {
    alarme("gas", false);

    if (isnan(temperatura))
    {
      temperatura = 100;
    }
    else
    { 
      if (temperatura >= TAXA_TEMP_MAX && temperatura < 100)
      {
        alarme("temperatura", true); 
      }
      else
      {
        alarme("temperatura", false); 
      }
    }
  }

  delay(2000);
}

void calibracaoX()
{
  sms_enviado = false;
  
  int i;
  float RS_air;

  digitalWrite(PIN_LED_INT, HIGH);

  for(i = 0; i < AVG; i++)
  {
    valorSensor = valorSensor + analogRead(PIN_SENSOR_GAS);
  }
  
  valorSensor = valorSensor / AVG;
 
  sensor_volt = valorSensor / 1024*5.0;
  
  RS_air = (5.0-sensor_volt) / sensor_volt;
  
  R0 = RS_air / 10.0;
    
  digitalWrite(PIN_LED_INT, LOW);
}

void alarme(String tipo_alarme, bool status_alarme)
{
  if (tipo_alarme == "gas" and status_alarme == true)
  {
    lcd.clear();
    lcd.print("AR CONTAMINADO!");
    saidas(true);
  }
  else if (tipo_alarme == "gas" and status_alarme == false)
  {
    lcd.clear();
    lcd.print("AR DESCONTAMINADO!");
    saidas(false);
  }
  else if (tipo_alarme == "temperatura" and status_alarme == true)
  {
    lcd.clear();
    lcd.setCursor(0,0);
    lcd.print("AR DESCONTAMINADO!");
    lcd.setCursor(0,1);
    lcd.print(temperatura);
    lcd.print("C (ALERTA!!!)");    
    saidas(true);
  }
  else if (tipo_alarme == "temperatura" and status_alarme == false)
  {
    lcd.clear();
    lcd.setCursor(0,0);
    lcd.print("AR DESCONTAMINADO!");
    lcd.setCursor(0,1);
    lcd.print(temperatura);
    lcd.print("C");
    saidas(false);
  }
}

void saidas(bool status_saida)
{
  if (status_saida == true)
  {
    digitalWrite(PIN_LED_ALERTA, HIGH);
    digitalWrite(PIN_BUZZER, HIGH);
  }
  else
  {
    digitalWrite(PIN_LED_ALERTA, LOW);
    digitalWrite(PIN_BUZZER, LOW);
  }
}

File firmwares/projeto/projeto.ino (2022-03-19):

#include <Scheduler.h>
#include <ESP8266WiFi.h>
#include <Wire.h>
#include <LiquidCrystal_I2C.h>
LiquidCrystal_I2C lcd(0x3F, 2, 1, 0, 4, 5, 6, 7, 3, POSITIVE);
#include <SensorTask.h>
#include "CrystalTask.h"
#include "WifiTask.h"

// GLOBAL : PINAGEM
#define PIN_BUZZER D3
#define PIN_LED_LAN D6
#define PIN_LED_ALERTA D7
#define PIN_LED_INT D8
#define PIN_INT D10

// GLOBAL : INTERRUPCAO
void ICACHE_RAM_ATTR calibracao();

// GLOBAL : CLASSES
CrystalTask crystalTask;
WifiTask wifiTask;
SensorTask sensorTask;

WiFiClient client;

void loop() {}

void setup() {
  WiFi.disconnect();
  
  Serial.begin(9600);

  lcd.begin(16, 2);

  // Interrupcao
  pinMode(PIN_INT, INPUT);

  // Leds
  pinMode(PIN_LED_INT, OUTPUT);
  pinMode(PIN_LED_ALERTA, OUTPUT);
  pinMode(PIN_LED_LAN, OUTPUT);

  // Buzzer
  pinMode(PIN_BUZZER, OUTPUT);

  // Seta nivel logico baixo dos leds
  digitalWrite(PIN_LED_INT, LOW);
  digitalWrite(PIN_LED_ALERTA, LOW);
  digitalWrite(PIN_LED_LAN, LOW);

  // Configura a interrupcao na borda de descida
  attachInterrupt(digitalPinToInterrupt(PIN_INT), calibracao, RISING);

  // Executa a funcao de calibracao
  calibracao();

  lcd.setBacklight(HIGH);
  lcd.setCursor(0, 0);
  lcd.print("INICIANDO.");

  for(int i=0; i<=2; i++) {
    delay(1000);
    lcd.print(".");
  }

  delay(1000);

  lcd.clear();
  lcd.print("CONECTANDO");

  WiFi.begin("Jr5G", "penadepato");

  while((!(WiFi.status() == WL_CONNECTED))) {
    delay(2000);
    lcd.print(".");
  }

  lcd.clear();

  digitalWrite(PIN_LED_LAN, HIGH);
  digitalWrite(PIN_BUZZER, HIGH);
  
  delay(100);
  
  digitalWrite(PIN_BUZZER, LOW);

  lcd.print("CONECTADO!!!");

  delay(3000);

  lcd.clear();
  lcd.print("VERIFICANDO AR");

  for(int i=0; i<=2; i++) {
    delay(2000);
    lcd.print(".");
  }

  lcd.clear();
  lcd.print("AR DESCONTAMINAD");

  // Escalonador de tarefas
  Scheduler.start(&crystalTask);
  Scheduler.start(&wifiTask); 
  Scheduler.start(&sensorTask); 
  
  Scheduler.begin();
}

void calibracao() {
  sensorTask.smsEnviado = false;
  
  digitalWrite(PIN_LED_INT, HIGH);

  for(int i=0; i<AVG; i++) {
    sensorTask.valorSensor = sensorTask.valorSensor + analogRead(PIN_SENSOR_GAS);
  }
  
  float rsAir;
  
  sensorTask.valorSensor = sensorTask.valorSensor / AVG;
  sensorTask.sensorVolt = sensorTask.sensorVolt / 1024*5.0; 
  rsAir = (5.0-sensorTask.sensorVolt) / sensorTask.sensorVolt;
  sensorTask.R0 = rsAir / 10.0;
    
  digitalWrite(PIN_LED_INT, LOW);
}

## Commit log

2022-03-10 inclusão de objetivo geral e especifico
2022-03-13 mudança na estrutura de diretorios
2022-03-13 mudanca na estrutura de arquivos
2022-03-19 docs: modifica documentacao v9
    [esquema_eletrico_eagle.sch, layout_da_pcb_eagle.brd, metricas_drills.csv]

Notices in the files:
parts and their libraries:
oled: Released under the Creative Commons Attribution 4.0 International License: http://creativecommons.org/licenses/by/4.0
